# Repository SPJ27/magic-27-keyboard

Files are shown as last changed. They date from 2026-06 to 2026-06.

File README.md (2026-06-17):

# Magic 27

Magic 27 is a aula f75 style keyboard designed completely from scrartch. It uses marbastlib, akko creamy blue switches, and 3d printed case.
I am building this because I wanted to make my own keyboard rather than buying premade ones. From this project, I learned skills such as cad designing, pcb designing, and a lot about mechanical keyboards.

Journal 5: ~3hrs
Completed the project! I designed the case, and also added the 3d models for different keys. Designing the case took a lot of time, and i have only designed the bottom holder for now. In, future, I will make the top cover if needed.


Journal 5: ~1hr 30mins
Routed all of the paths, fixed some errors, and the pcb is ready. I had to reroute twice cause the paths were colliding. Routing had taken a lot of time, because I had to connect each of them individually.


Journal 4: ~1hr 30mins

Added all of diodes - it was extremely time consuming as I had to place them individually. Also, I have started making the basic routes.


Journal 3: ~1hr

So I remade the pcb as it got corrupted the last time. This time it took way less time as compared to the previous version as I already knew things that i should have done earlier - for example i should have named the components by there key for easier positioning and whatnot.


Journal 2: ~3hrs 30mins

I switched from kicad 8.0 to kicad 10, so my original work with pcb is now showing as corrupted when I woke up this morning. I have a few screenshots of prev versions.



Journal 1: ~1hr 50mins

Created the basic pcb - will now rearrange and rename all of the switches, and then arrange all of them in pcb editor.


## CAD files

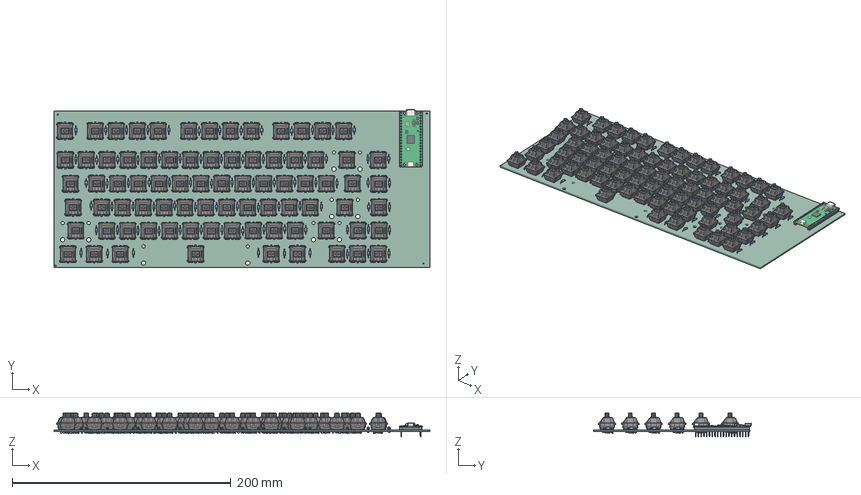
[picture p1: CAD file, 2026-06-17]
magic27.step
343.5 x 144.1 x 21.6 mm
D_DO-35_SOD27_P7.62mm_Horizontal x 80
MX1A-11NN x 80
RaspberryPi_Pico_H_Module_KiCad
RaspberryPi_Pico_Header_DIP-40_H2.54mm_KiCad
magic-27_PCB

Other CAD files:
magic27.stl

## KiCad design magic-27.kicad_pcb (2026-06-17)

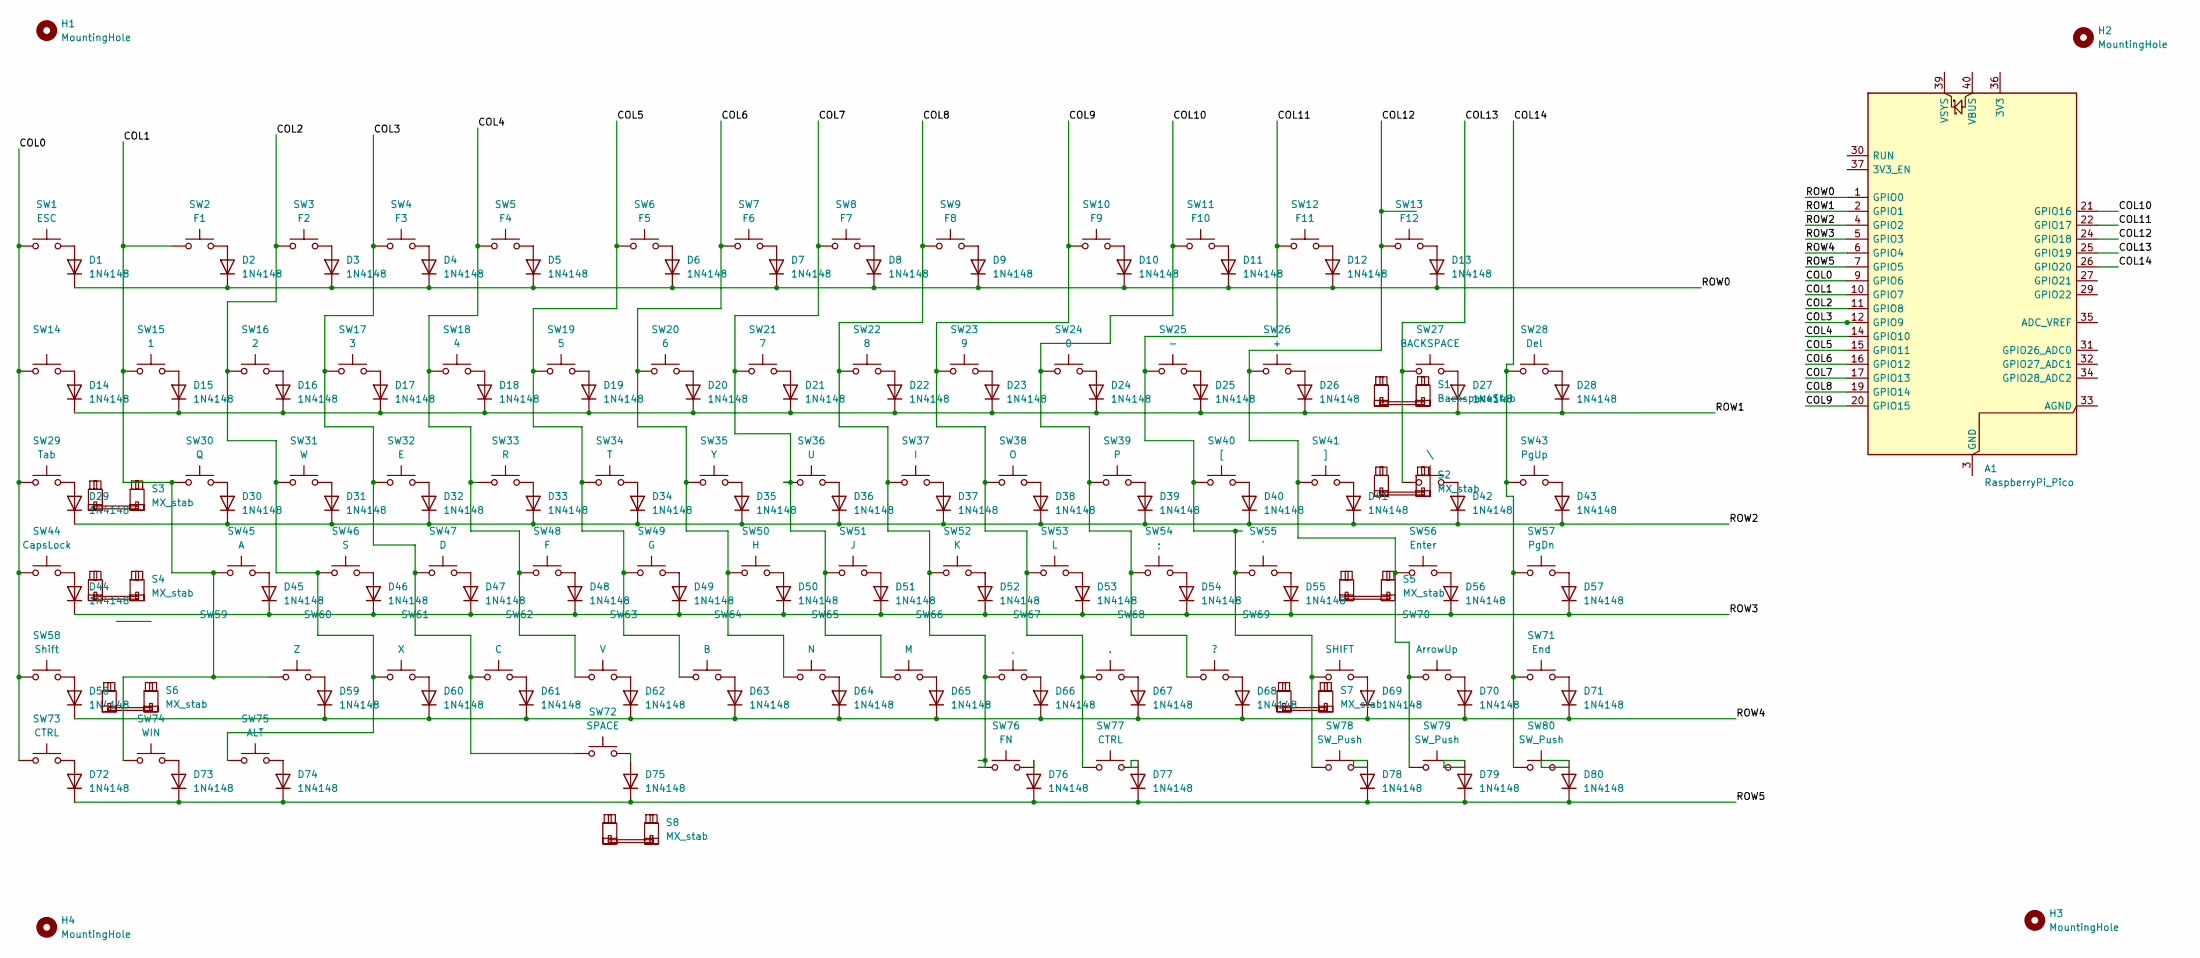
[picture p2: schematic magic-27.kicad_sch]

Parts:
A1: RaspberryPi_Pico; RaspberryPi_Pico_Common_THT
D1, D2, D3, D4, D5, D6, D7, D8, D9, D10, D11, D12, D13, D14, D15, D16, D17, D18, D19, D20, D21, D22, D23, D24, D25, D26, D27, D28, D29, D30, D31, D32, D33, D34, D35, D36, D37, D38, D39, D40, D41, D42, D43, D44, D45, D46, D47, D48, D49, D50, D51, D52, D53, D54, D55, D56, D57, D58, D59, D60, D61, D62, D63, D64, D65, D66, D67, D68, D69, D70, D71, D72, D73, D74, D75, D76, D77, D78, D79, D80: 1N4148; D_DO-35_SOD27_P7.62mm_Horizontal
H1, H2, H3, H4: MountingHole; ToolingHole_1.152mm
S1: BackspaceStab; STAB_MX_2u
S2, S6, S7: MX_stab; STAB_MX_2u
S3, S4: MX_stab; STAB_MX_2.25u
S5: MX_stab; STAB_MX_2.75u
S8: MX_stab; STAB_MX_6u
SW1: ESC; SW_MX_1u
SW2: F1; SW_MX_1u
SW3: F2; SW_MX_1u
SW4: F3; SW_MX_1u
SW5: F4; SW_MX_1u
SW6: F5; SW_MX_1u
SW7: F6; SW_MX_1u
SW8: F7; SW_MX_1u
SW9: F8; SW_MX_1u
SW10: F9; SW_MX_1u
SW11: F10; SW_MX_1u
SW12: F11; SW_MX_1u
SW13: F12; SW_MX_1u
SW14: SW_MX_1u
SW15: 1; SW_MX_1u
SW16: 2; SW_MX_1u
SW17: 3; SW_MX_1u
SW18: 4; SW_MX_1u
SW19: 5; SW_MX_1u
SW20: 6; SW_MX_1u
SW21: 7; SW_MX_1u
SW22: 8; SW_MX_1u
SW23: 9; SW_MX_1u
SW24: 0; SW_MX_1u
SW25: -; SW_MX_1u
SW26: +; SW_MX_1u
SW27: BACKSPACE; SW_MX_1u
SW28: Del; SW_MX_1u
SW29: Tab; SW_MX_1.5u
SW30: Q; SW_MX_1u
SW31: W; SW_MX_1u
SW32: E; SW_MX_1u
SW33: R; SW_MX_1u
SW34: T; SW_MX_1u
SW35: Y; SW_MX_1u
SW36: U; SW_MX_1u
SW37: I; SW_MX_1u
SW38: O; SW_MX_1u
SW39: P; SW_MX_1u
SW40: [; SW_MX_1u
SW41: ]; SW_MX_1u
SW42: \; SW_MX_1.5u
SW43: PgUp; SW_MX_1u
SW44: CapsLock; SW_MX_1.75u
SW45: A; SW_MX_1u
SW46: S; SW_MX_1u
SW47: D; SW_MX_1u
SW48: F; SW_MX_1u
SW49: G; SW_MX_1u
SW50: H; SW_MX_1u
SW51: J; SW_MX_1u
SW52: K; SW_MX_1u
SW53: L; SW_MX_1u
SW54: ;; SW_MX_1u
SW55: '; SW_MX_1u
SW56: Enter; SW_MX_1u
SW57: PgDn; SW_MX_1u
SW58: Shift; SW_MX_1u
SW59: Z; SW_MX_1u
SW60: X; SW_MX_1u
SW61: C; SW_MX_1u
SW62: V; SW_MX_1u
SW63: B; SW_MX_1u
SW64: N; SW_MX_1u
SW65: M; SW_MX_1u
SW66: ,; SW_MX_1u
SW67: .; SW_MX_1u
SW68: ?; SW_MX_1u
SW69: SHIFT; SW_MX_1u
SW70: ArrowUp; SW_MX_1u
SW71: End; SW_MX_1u
SW72: SPACE; SW_MX_1u
SW73, SW77: CTRL; SW_MX_1.25u
SW74: WIN; SW_MX_1.25u
SW75: ALT; SW_MX_1.25u
SW76: FN; SW_MX_1.25u
SW78, SW79, SW80: SW_Push; SW_MX_1u

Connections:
/COL0: A1.9 (GPIO6), SW1.1, SW14.1, SW29.1, SW44.1, SW58.1, SW73.1
/COL1: A1.10 (GPIO7), SW2.1, SW15.1, SW30.1, SW45.1, SW59.1, SW74.1
/COL2: A1.11 (GPIO8), SW3.1, SW16.1, SW31.1, SW46.1, SW60.1, SW75.1
/COL3: A1.12 (GPIO9), SW4.1, SW17.1, SW32.1, SW47.1, SW61.1, SW72.1
/COL4: A1.14 (GPIO10), SW5.1, SW18.1, SW33.1, SW48.1, SW62.1
/COL5: A1.15 (GPIO11), SW6.1, SW19.1, SW34.1, SW49.1, SW63.1
/COL6: A1.16 (GPIO12), SW7.1, SW20.1, SW35.1, SW50.1, SW64.1
/COL7: A1.17 (GPIO13), SW8.1, SW21.1, SW36.1, SW51.1, SW65.1
/COL8: A1.19 (GPIO14), SW9.1, SW22.1, SW37.1, SW52.1, SW66.1, SW76.1
/COL9: A1.20 (GPIO15), SW10.1, SW23.1, SW38.1, SW53.1, SW67.1, SW77.1
/COL10: A1.21 (GPIO16), SW11.1, SW24.1, SW39.1, SW54.1, SW68.1
/COL11: A1.22 (GPIO17), SW12.1, SW25.1, SW40.1, SW55.1, SW69.1, SW78.1
/COL12: A1.24 (GPIO18), SW13.1, SW26.1, SW41.1, SW56.1, SW70.1, SW79.1
/COL13: A1.25 (GPIO19), SW27.1, SW42.1
/COL14: A1.26 (GPIO20), SW28.1, SW43.1, SW57.1, SW71.1, SW80.1
/ROW0: A1.1 (GPIO0), D1.1 (K), D2.1 (K), D3.1 (K), D4.1 (K), D5.1 (K), D6.1 (K), D7.1 (K), D8.1 (K), D9.1 (K), D10.1 (K), D11.1 (K), D12.1 (K), D13.1 (K)
/ROW1: A1.2 (GPIO1), D14.1 (K), D15.1 (K), D16.1 (K), D17.1 (K), D18.1 (K), D19.1 (K), D20.1 (K), D21.1 (K), D22.1 (K), D23.1 (K), D24.1 (K), D25.1 (K), D26.1 (K), D27.1 (K), D28.1 (K)
/ROW2: A1.4 (GPIO2), D29.1 (K), D30.1 (K), D31.1 (K), D32.1 (K), D33.1 (K), D34.1 (K), D35.1 (K), D36.1 (K), D37.1 (K), D38.1 (K), D39.1 (K), D40.1 (K), D41.1 (K), D42.1 (K), D43.1 (K)
/ROW3: A1.5 (GPIO3), D44.1 (K), D45.1 (K), D46.1 (K), D47.1 (K), D48.1 (K), D49.1 (K), D50.1 (K), D51.1 (K), D52.1 (K), D53.1 (K), D54.1 (K), D55.1 (K), D56.1 (K), D57.1 (K)
/ROW4: A1.6 (GPIO4), D58.1 (K), D59.1 (K), D60.1 (K), D61.1 (K), D62.1 (K), D63.1 (K), D64.1 (K), D65.1 (K), D66.1 (K), D67.1 (K), D68.1 (K), D69.1 (K), D70.1 (K), D71.1 (K)
/ROW5: A1.7 (GPIO5), D72.1 (K), D73.1 (K), D74.1 (K), D75.1 (K), D76.1 (K), D77.1 (K), D78.1 (K), D79.1 (K), D80.1 (K)
unnamed: A1.3 (GND), A1.8 (GND), A1.13 (GND), A1.18 (GND), A1.23 (GND), A1.28 (GND), A1.38 (GND)
unnamed: D1.2 (A), SW1.2
unnamed: D2.2 (A), SW2.2
unnamed: D3.2 (A), SW3.2
unnamed: D4.2 (A), SW4.2
unnamed: D5.2 (A), SW5.2
unnamed: D6.2 (A), SW6.2
unnamed: D7.2 (A), SW7.2
unnamed: D8.2 (A), SW8.2
unnamed: D9.2 (A), SW9.2
unnamed: D10.2 (A), SW10.2
unnamed: D11.2 (A), SW11.2
unnamed: D12.2 (A), SW12.2
unnamed: D13.2 (A), SW13.2
unnamed: D14.2 (A), SW14.2
unnamed: D15.2 (A), SW15.2
unnamed: D16.2 (A), SW16.2
unnamed: D17.2 (A), SW17.2
unnamed: D18.2 (A), SW18.2
unnamed: D19.2 (A), SW19.2
unnamed: D20.2 (A), SW20.2
unnamed: D21.2 (A), SW21.2
unnamed: D22.2 (A), SW22.2
unnamed: D23.2 (A), SW23.2
unnamed: D24.2 (A), SW24.2
unnamed: D25.2 (A), SW25.2
unnamed: D26.2 (A), SW26.2
unnamed: D27.2 (A), SW27.2
unnamed: D28.2 (A), SW28.2
unnamed: D29.2 (A), SW29.2
unnamed: D30.2 (A), SW30.2
unnamed: D31.2 (A), SW31.2
unnamed: D32.2 (A), SW32.2
unnamed: D33.2 (A), SW33.2
unnamed: D34.2 (A), SW34.2
unnamed: D35.2 (A), SW35.2
unnamed: D36.2 (A), SW36.2
unnamed: D37.2 (A), SW37.2
unnamed: D38.2 (A), SW38.2
unnamed: D39.2 (A), SW39.2
unnamed: D40.2 (A), SW40.2
unnamed: D41.2 (A), SW41.2
unnamed: D42.2 (A), SW42.2
unnamed: D43.2 (A), SW43.2
unnamed: D44.2 (A), SW44.2
unnamed: D45.2 (A), SW45.2
unnamed: D46.2 (A), SW46.2
unnamed: D47.2 (A), SW47.2
unnamed: D48.2 (A), SW48.2
unnamed: D49.2 (A), SW49.2
unnamed: D50.2 (A), SW50.2
unnamed: D51.2 (A), SW51.2
unnamed: D52.2 (A), SW52.2
unnamed: D53.2 (A), SW53.2
unnamed: D54.2 (A), SW54.2
unnamed: D55.2 (A), SW55.2
unnamed: D56.2 (A), SW56.2
unnamed: D57.2 (A), SW57.2
unnamed: D58.2 (A), SW58.2
unnamed: D59.2 (A), SW59.2
unnamed: D60.2 (A), SW60.2
unnamed: D61.2 (A), SW61.2
unnamed: D62.2 (A), SW62.2
unnamed: D63.2 (A), SW63.2
unnamed: D64.2 (A), SW64.2
unnamed: D65.2 (A), SW65.2
unnamed: D66.2 (A), SW66.2
unnamed: D67.2 (A), SW67.2
unnamed: D68.2 (A), SW68.2
unnamed: D69.2 (A), SW69.2
unnamed: D70.2 (A), SW70.2
unnamed: D71.2 (A), SW71.2
unnamed: D72.2 (A), SW73.2
unnamed: D73.2 (A), SW74.2
unnamed: D74.2 (A), SW75.2
unnamed: D75.2 (A), SW72.2
unnamed: D76.2 (A), SW76.2
unnamed: D77.2 (A), SW77.2
unnamed: D78.2 (A), SW78.2
unnamed: D79.2 (A), SW79.2
unnamed: D80.2 (A), SW80.2

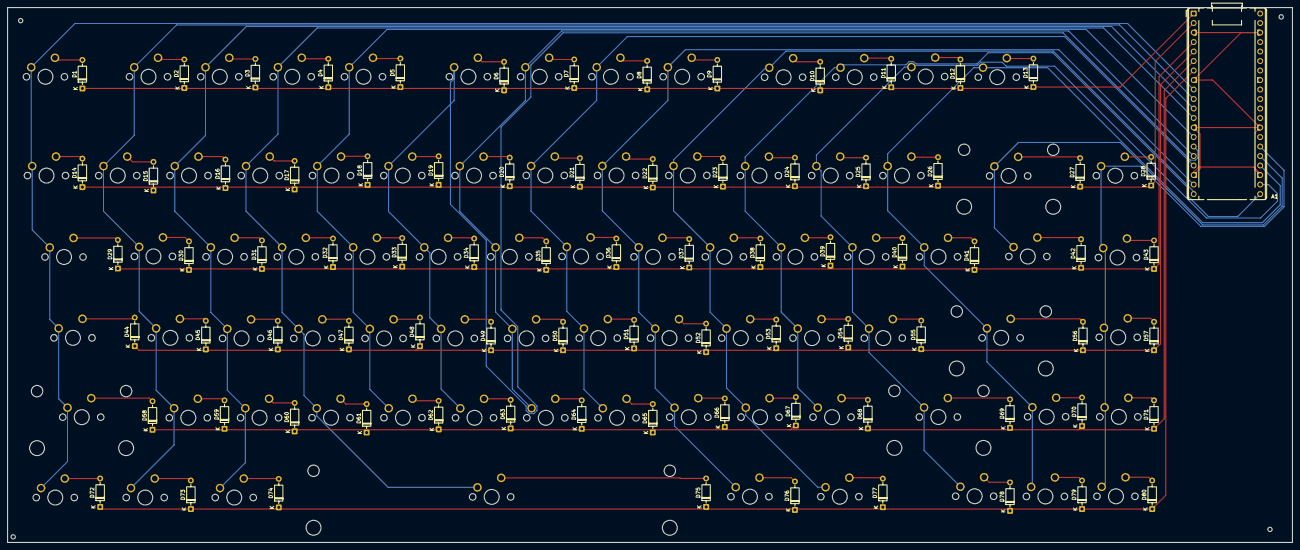
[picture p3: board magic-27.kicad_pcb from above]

Board: 2 copper layers, 343.5 x 143.0 mm, 170 parts (0 on the bottom side), 102 nets.
